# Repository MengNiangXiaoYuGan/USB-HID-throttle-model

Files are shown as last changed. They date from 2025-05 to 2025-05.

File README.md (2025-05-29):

# USB-HID-throttle-model

该仓库作为USB-HID-throttle项目的模型仓库,仓库内文件夹结构如下

|

|\  模型        //用于放置需要打印的文件

|   

|-  LICENSE     //许可证文件

|

|-  MNXYG_出图-装配.pdf     //总装配的工程图，五金件表单以及打印要求和热嵌螺母安装位也在里面

另外，为了制造具有完整功能的USB-HID节流阀，还需要制造电路板以及下载程序。
电路板程序可以从以下仓库获得
https://github.com/MengNiangXiaoYuGan/USB-HID-throttle-PCB.git

程序源码可以在以下仓库获得，或者在电路板仓库中直接使用已经编译好的bin文件
https://github.com/MengNiangXiaoYuGan/USB-HID-throttle-program.git

祝，使用愉快，有问题请反馈，有闲心会看一下

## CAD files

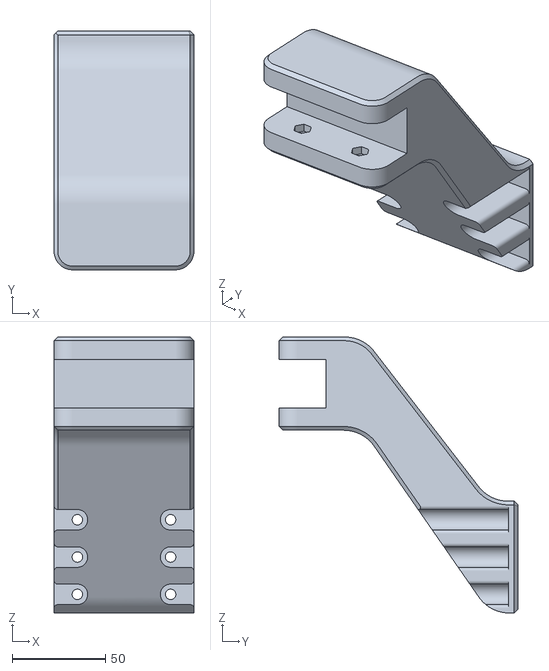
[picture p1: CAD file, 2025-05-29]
模型/私有油门-桌面连接件-M5大小.stl
75.0 x 128.0 x 148.0

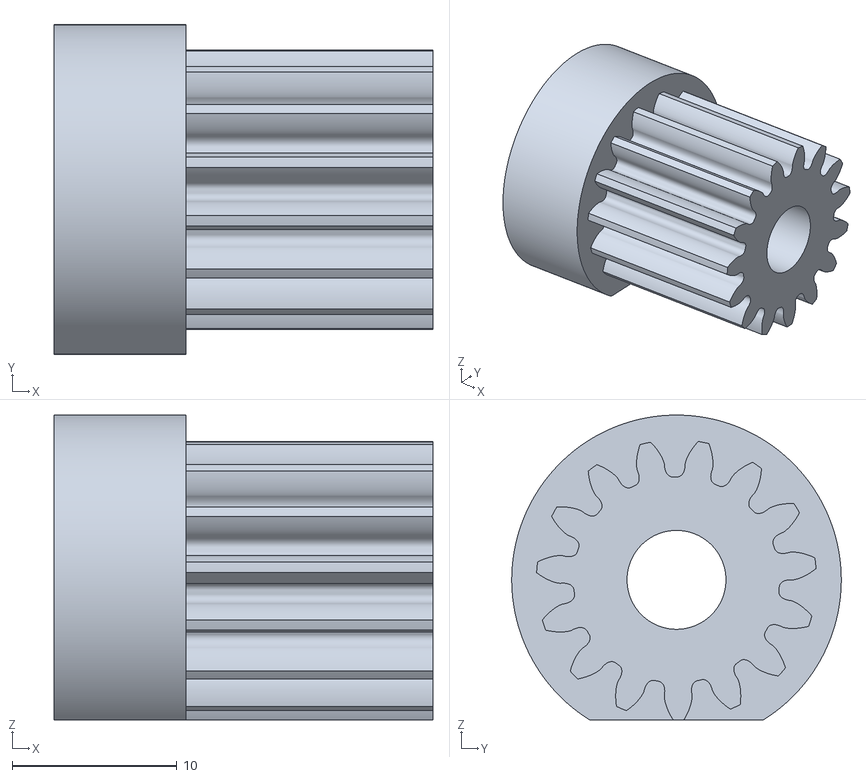
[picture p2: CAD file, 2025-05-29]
模型/电位器齿轮.stl
23.0 x 20.0 x 18.5

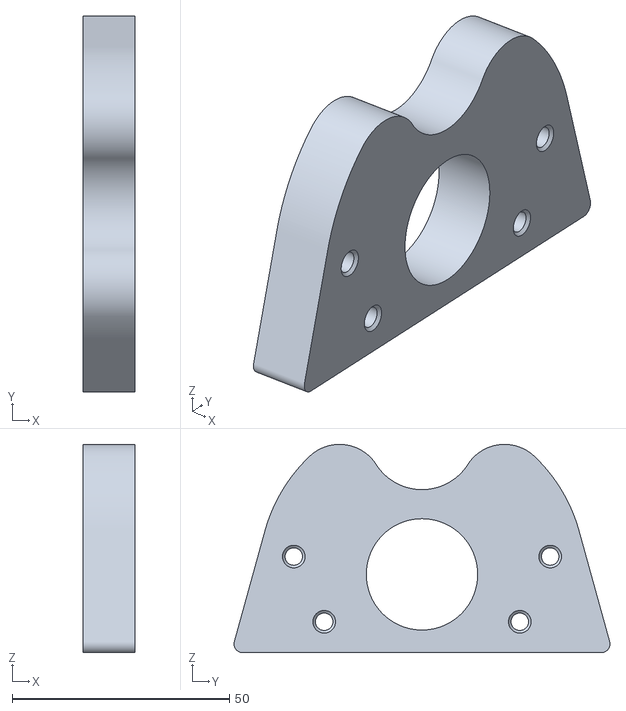
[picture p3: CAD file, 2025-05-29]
模型/底座-油门连接杆-环套.stl
12.0 x 86.5 x 47.9

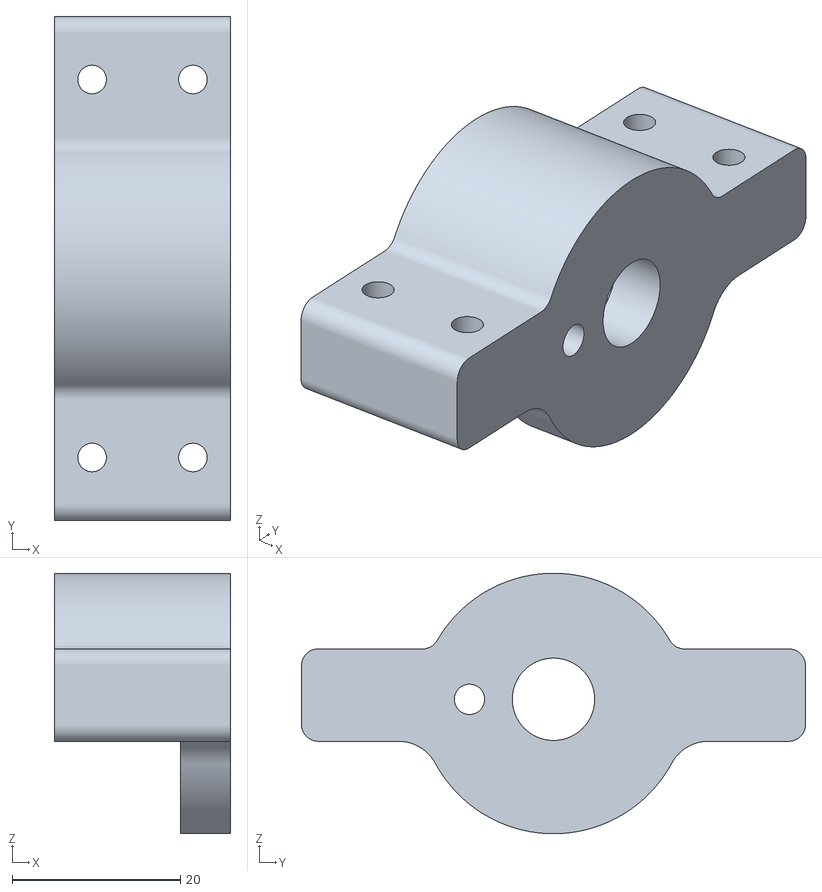
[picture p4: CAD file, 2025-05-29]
模型/电位器-连接件.stl
21.0 x 60.0 x 31.0

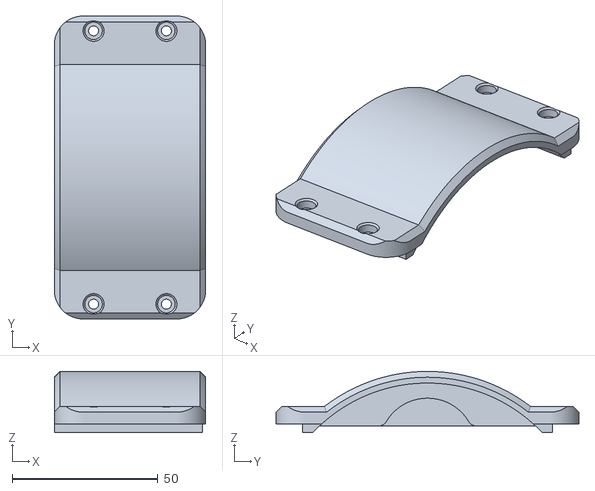
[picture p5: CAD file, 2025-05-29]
模型/底座-电位器齿轮上盖.stl
52.0 x 104.0 x 21.0

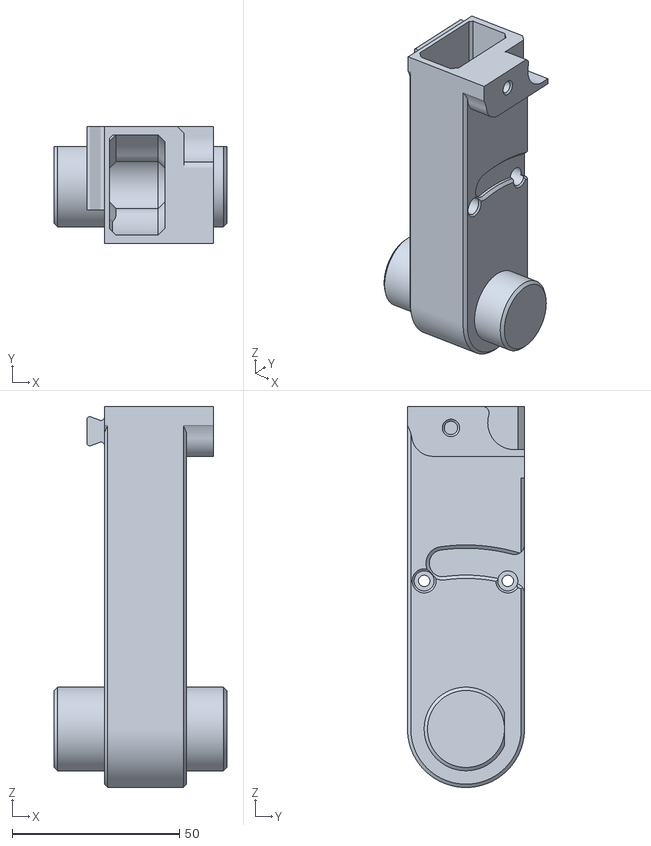
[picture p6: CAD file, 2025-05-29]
模型/手把-连接杆.stl
51.6 x 35.0 x 113.9

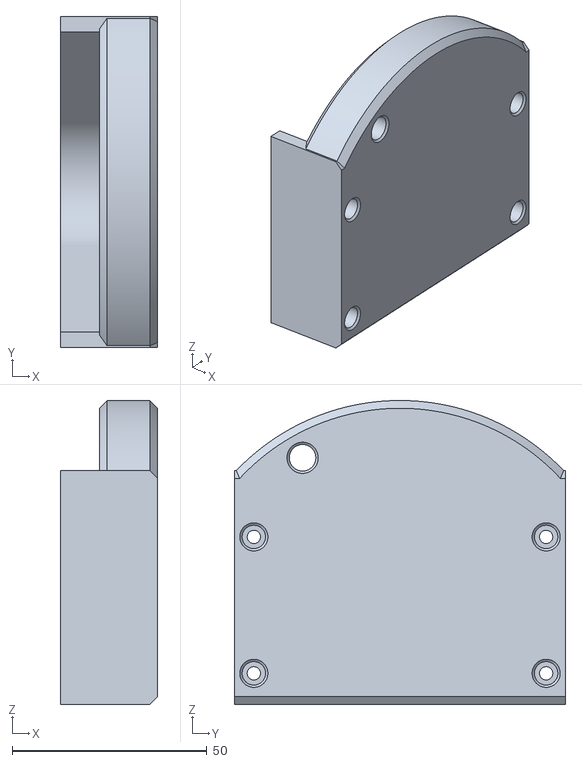
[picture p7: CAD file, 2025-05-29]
模型/底座-油门连接杆-外封.stl
25.0 x 85.0 x 78.0

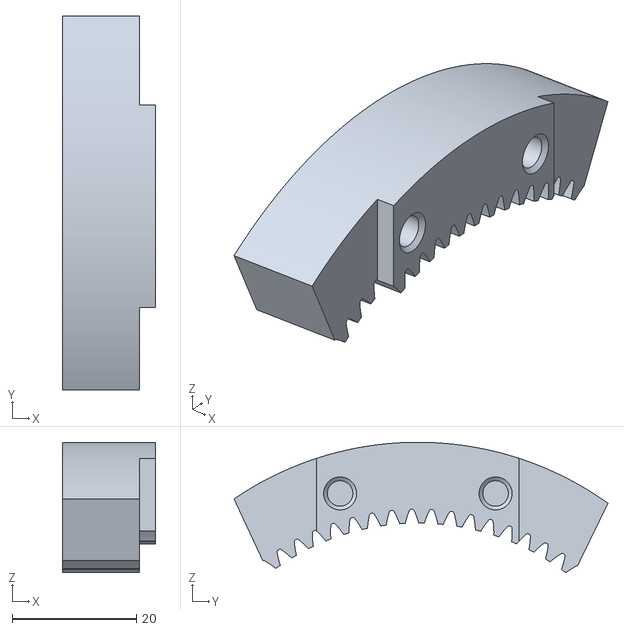
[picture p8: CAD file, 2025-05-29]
模型/手把-主动齿条.stl
15.0 x 60.1 x 21.0

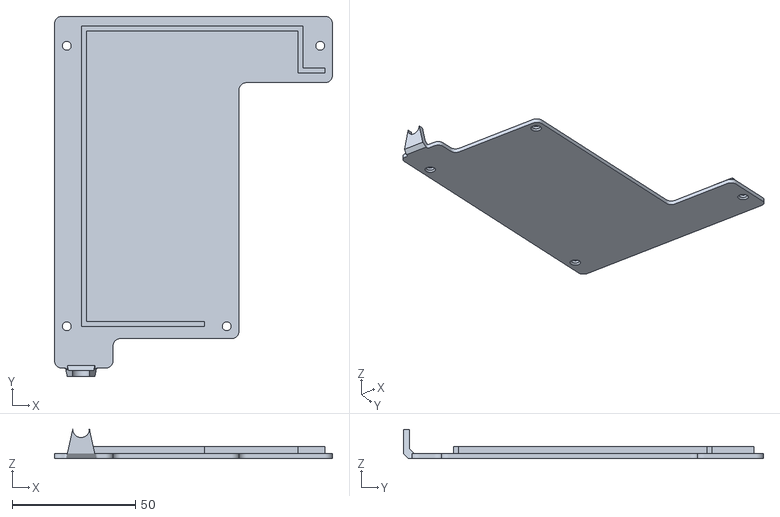
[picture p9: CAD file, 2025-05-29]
模型/底座-下盖.stl
113.0 x 146.5 x 11.9

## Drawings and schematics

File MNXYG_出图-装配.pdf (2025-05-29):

# USB

# HID

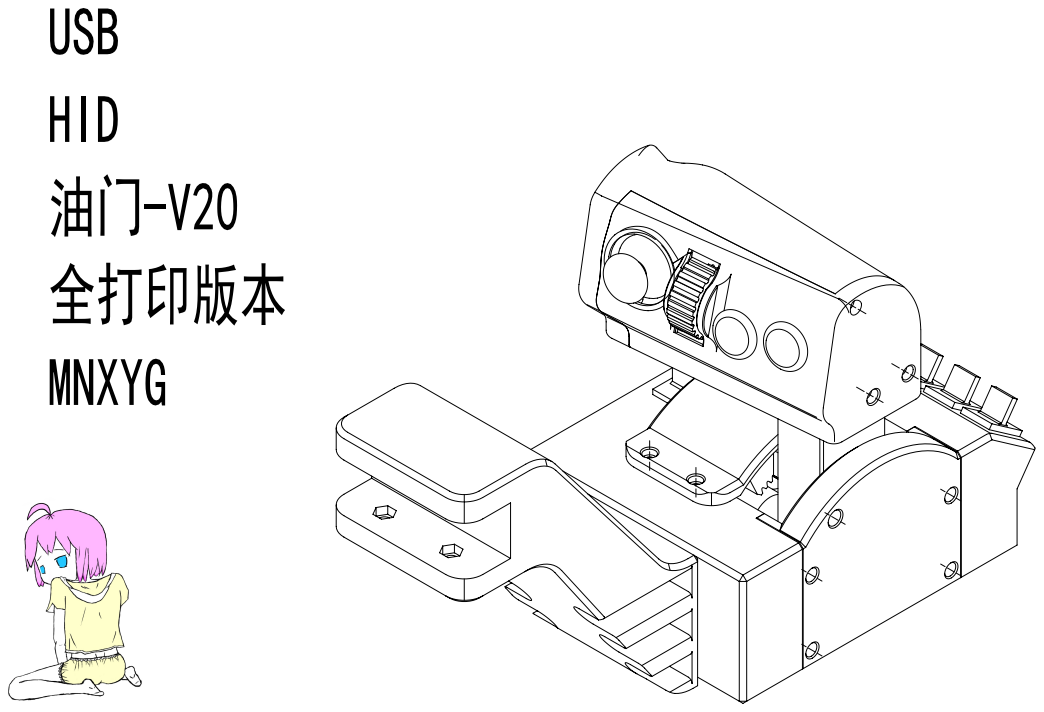
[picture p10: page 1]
全打印版本 MNXYG

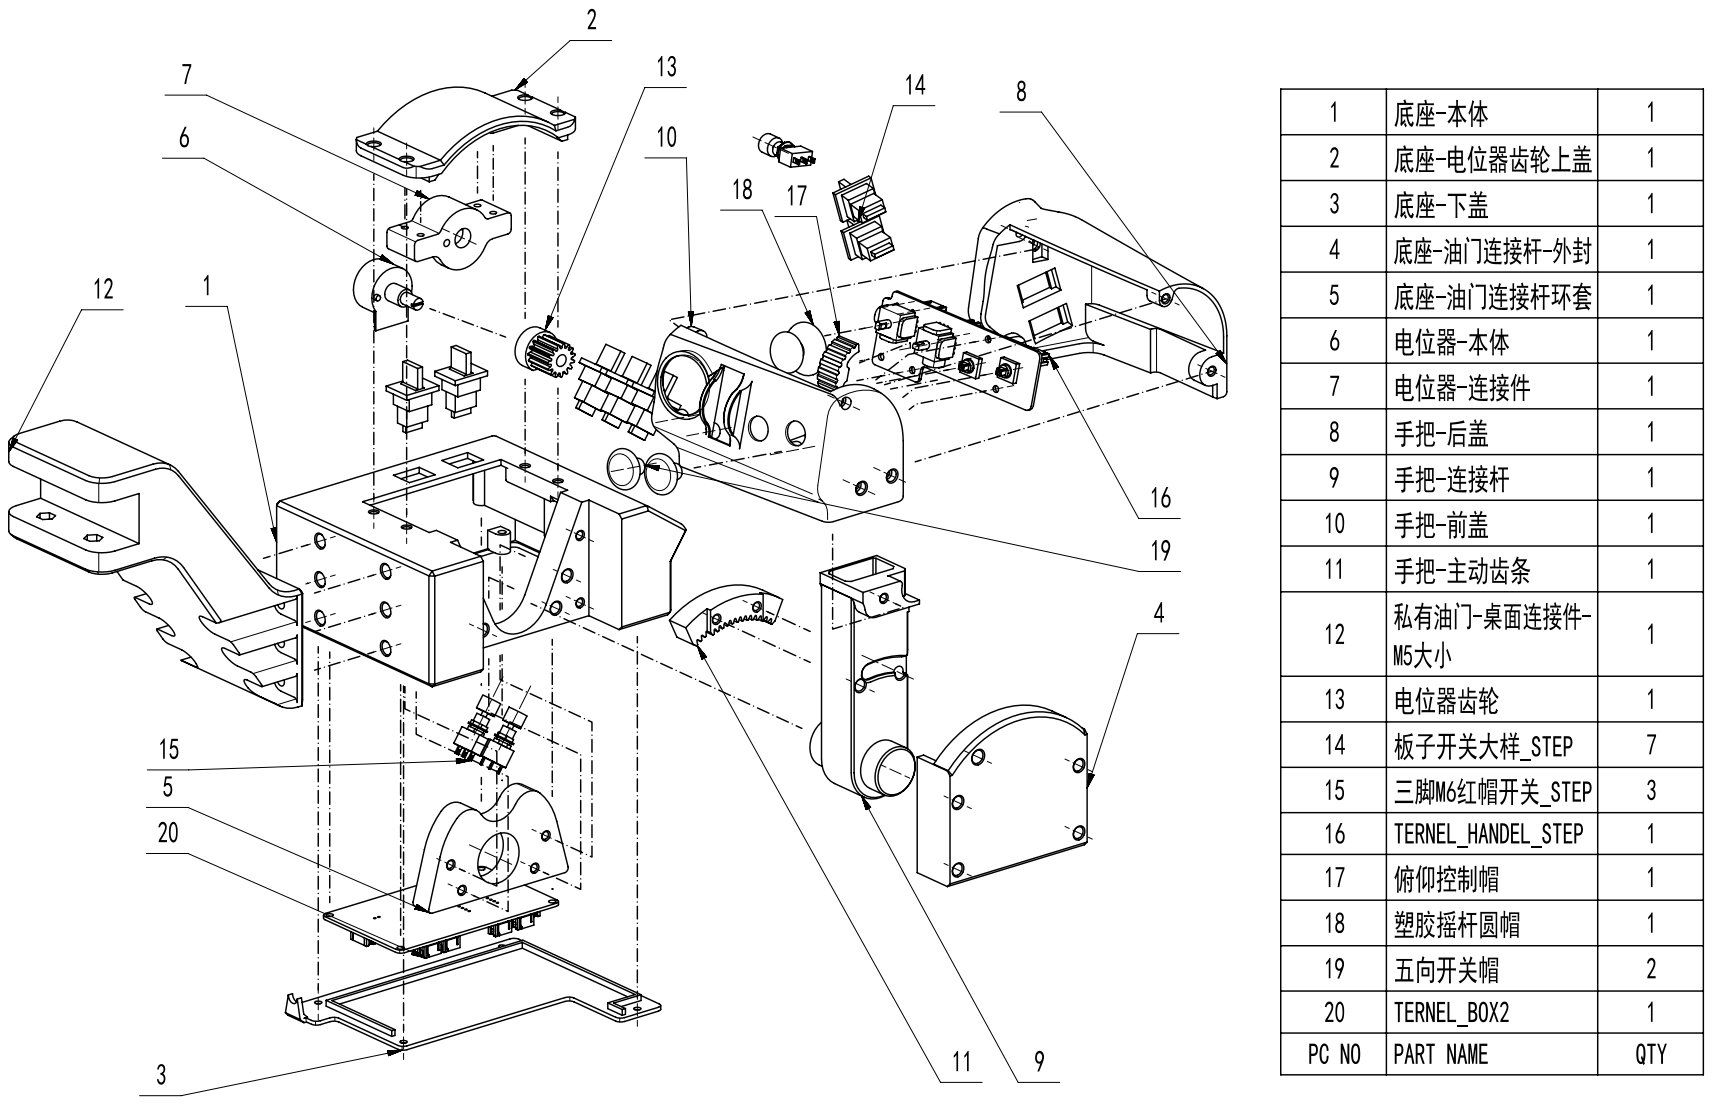
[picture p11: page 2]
底座-电位器齿轮上盖; 底座-油门连接杆-外封; 底座-油门连接杆环套; 电位器-本体; 电位器-连接件; 手把-连接杆; 手把-主动齿条; 私有油门-桌面连接件-; 电位器齿轮; 板子开关大样_STEP; 三脚M6红帽开关_STEP; TERNEL_HANDEL_STEP; 俯仰控制帽; 塑胶摇杆圆帽; 五向开关帽; TERNEL_BOX2; PART NAME; QTY

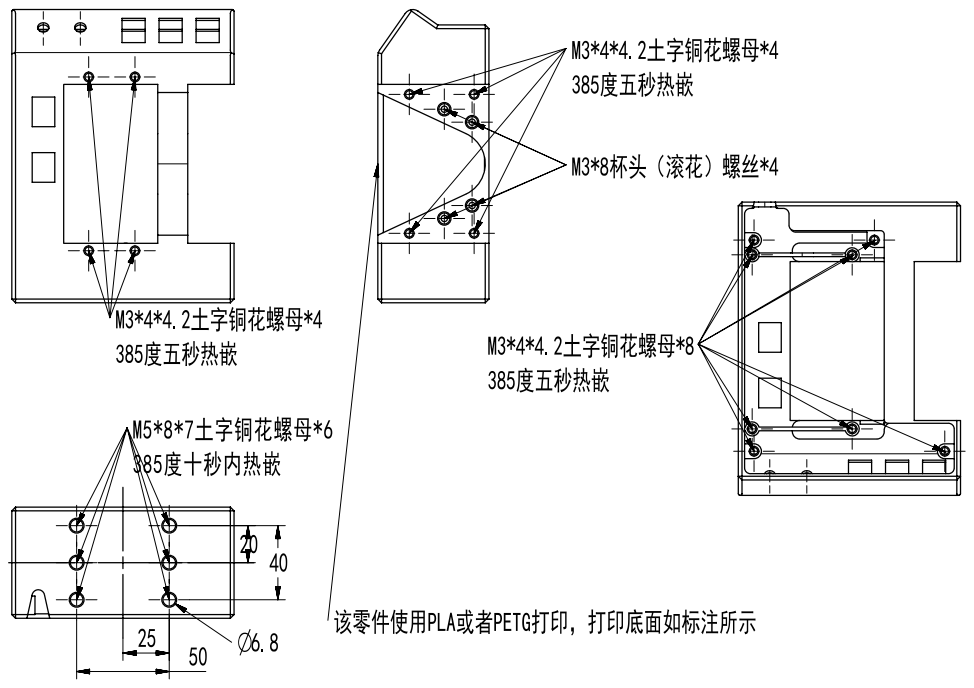
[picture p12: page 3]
M5*8*7土字铜花螺母*6; 385度十秒内热嵌; M3*4*4.2土字铜花螺母*4; 385度五秒热嵌; M3*4*4.2土字铜花螺母*8; 该零件使用PLA或者PETG打印，打印底面如标注所示

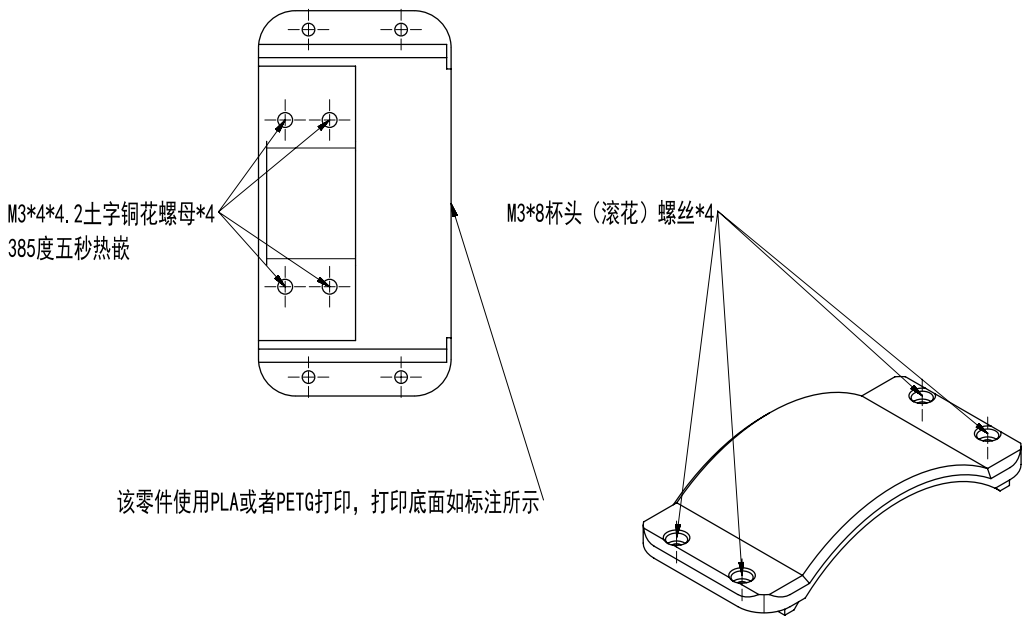
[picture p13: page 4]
M3*4*4.2土字铜花螺母*4; 385度五秒热嵌; 该零件使用PLA或者PETG打印，打印底面如标注所示

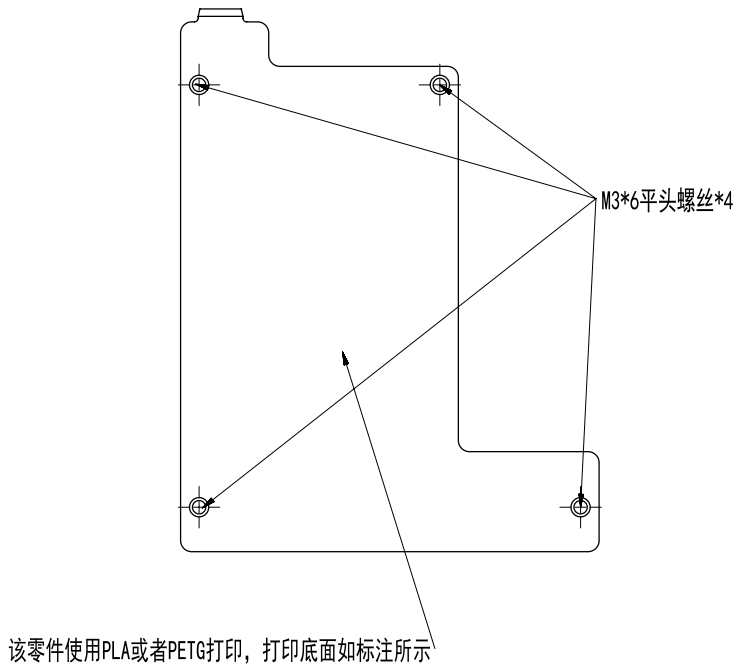
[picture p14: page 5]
M3*6平头螺丝*4; 该零件使用PLA或者PETG打印，打印底面如标注所示

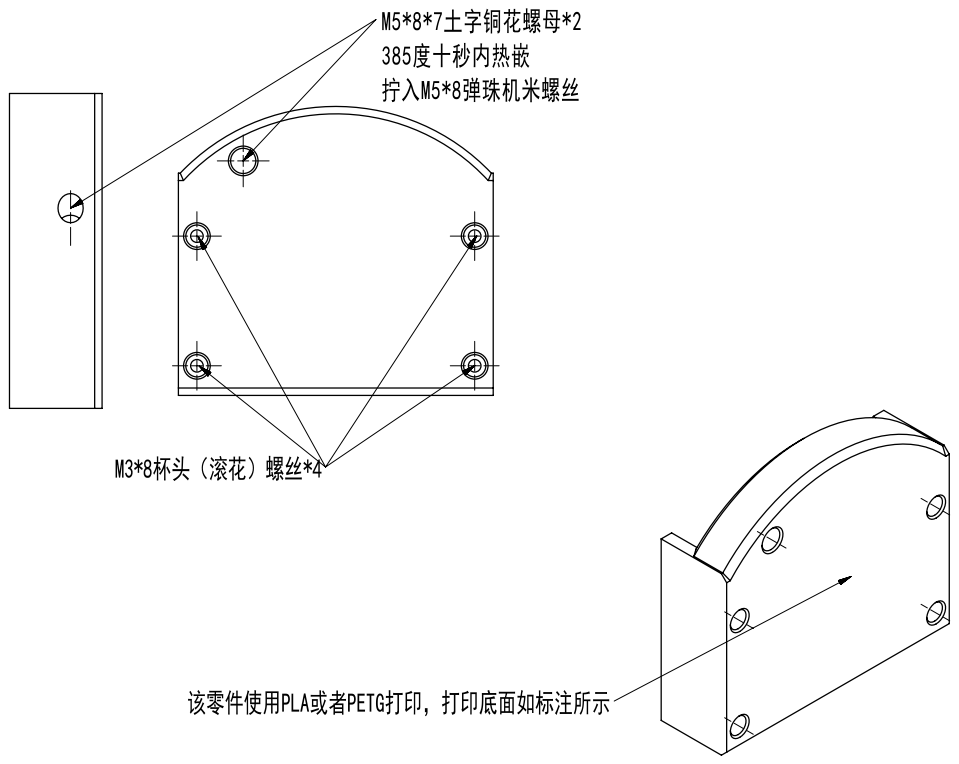
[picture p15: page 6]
该零件使用PLA或者PETG打印，打印底面如标注所示; M5*8*7土字铜花螺母*2; 385度十秒内热嵌 拧入M5*8弹珠机米螺丝

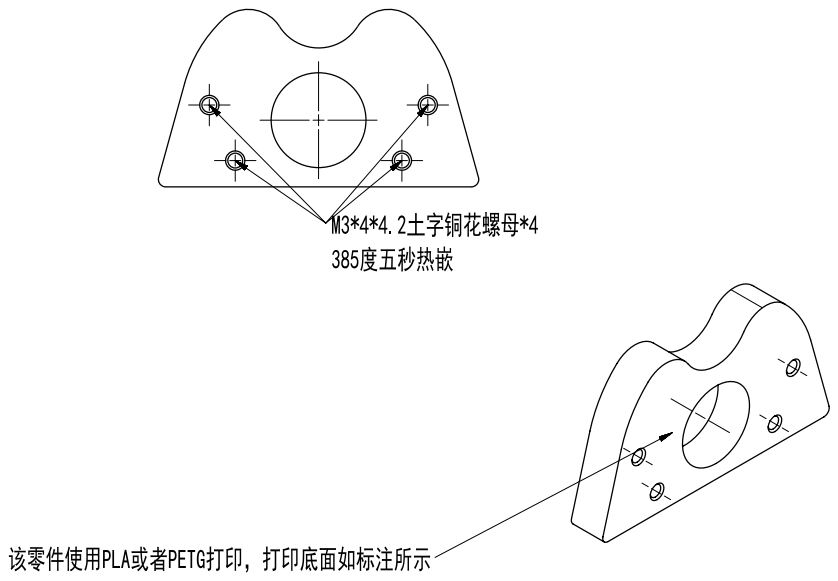
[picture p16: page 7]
该零件使用PLA或者PETG打印，打印底面如标注所示; M3*4*4.2土字铜花螺母*4; 385度五秒热嵌

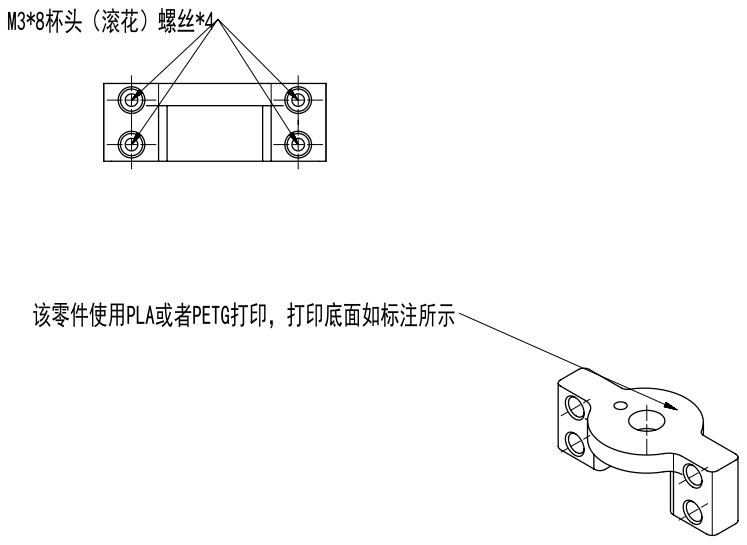
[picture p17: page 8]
该零件使用PLA或者PETG打印，打印底面如标注所示

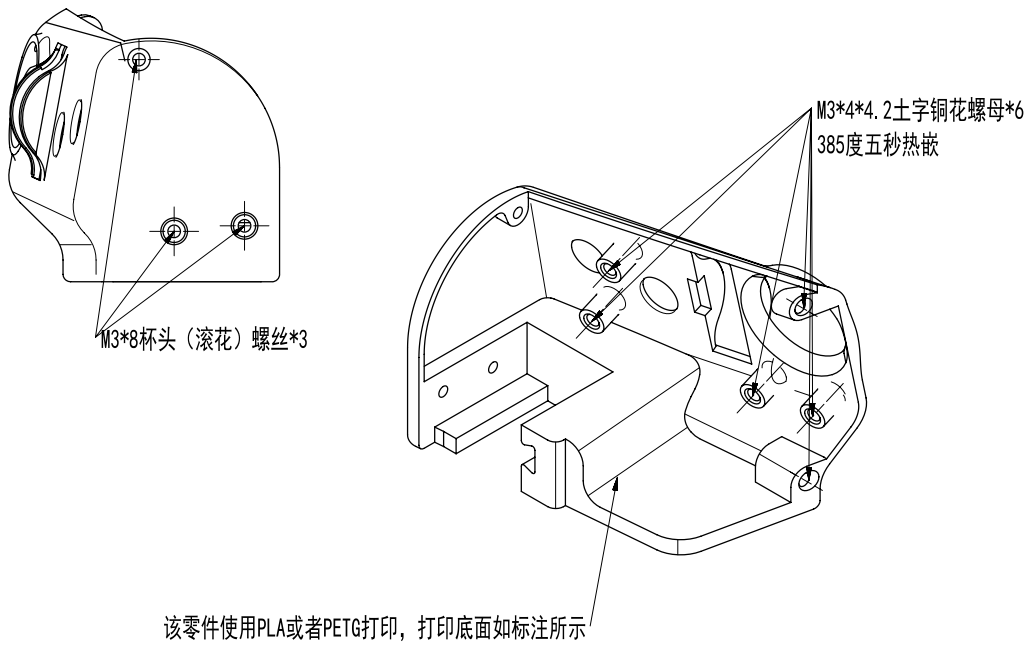
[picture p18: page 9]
M3*4*4.2土字铜花螺母*6; 385度五秒热嵌; 该零件使用PLA或者PETG打印，打印底面如标注所示

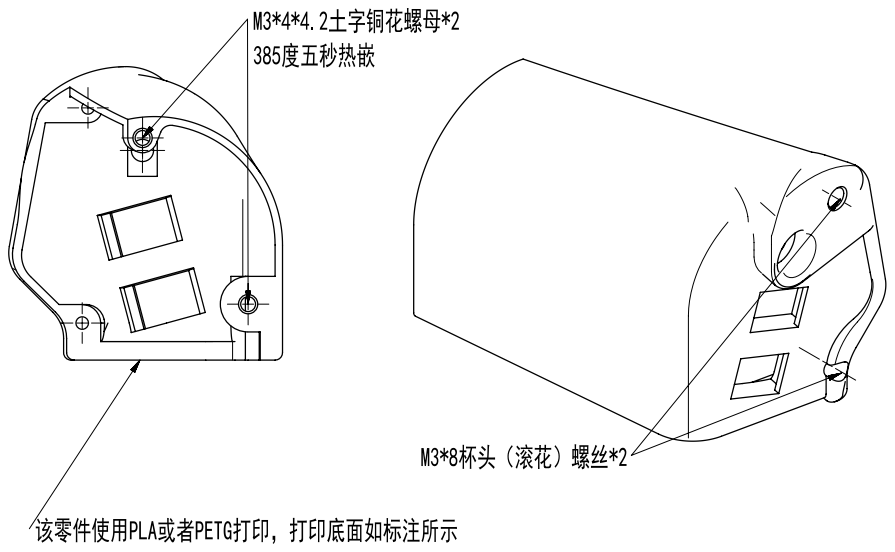
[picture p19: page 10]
M3*4*4.2土字铜花螺母*2; 385度五秒热嵌; 该零件使用PLA或者PETG打印，打印底面如标注所示

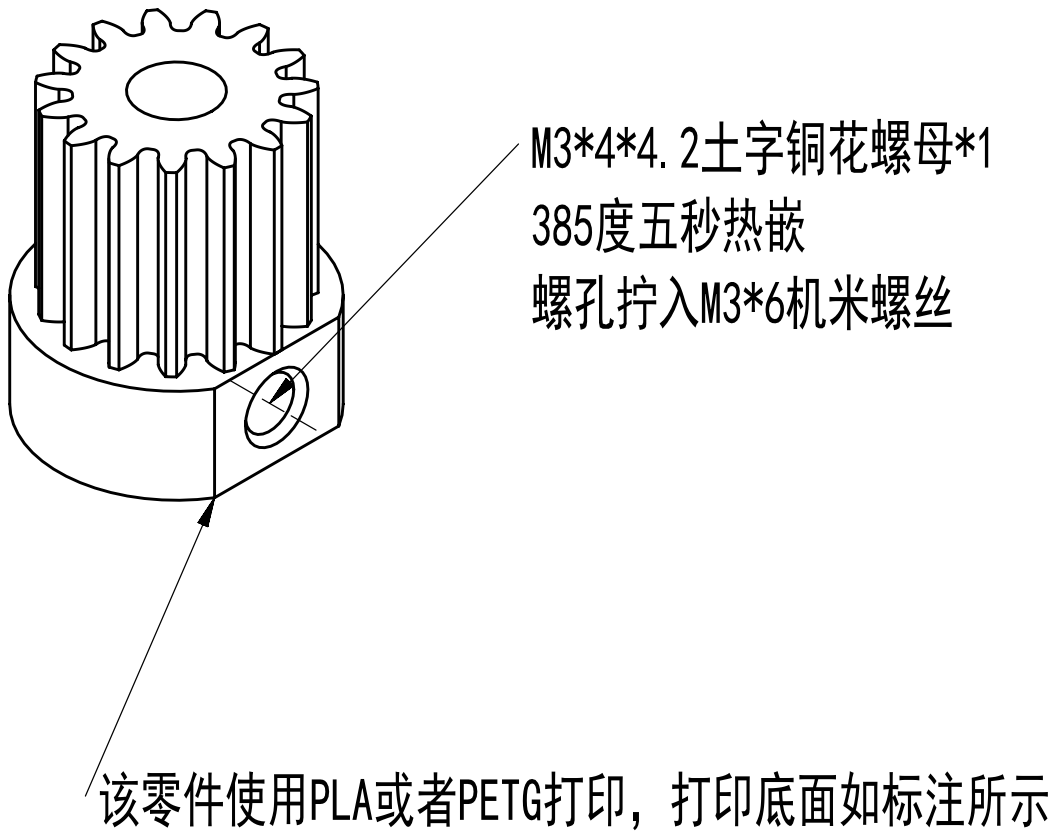
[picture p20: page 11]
M3*4*4.2土字铜花螺母*1; 385度五秒热嵌 螺孔拧入M3*6机米螺丝; 该零件使用PLA或者PETG打印，打印底面如标注所示

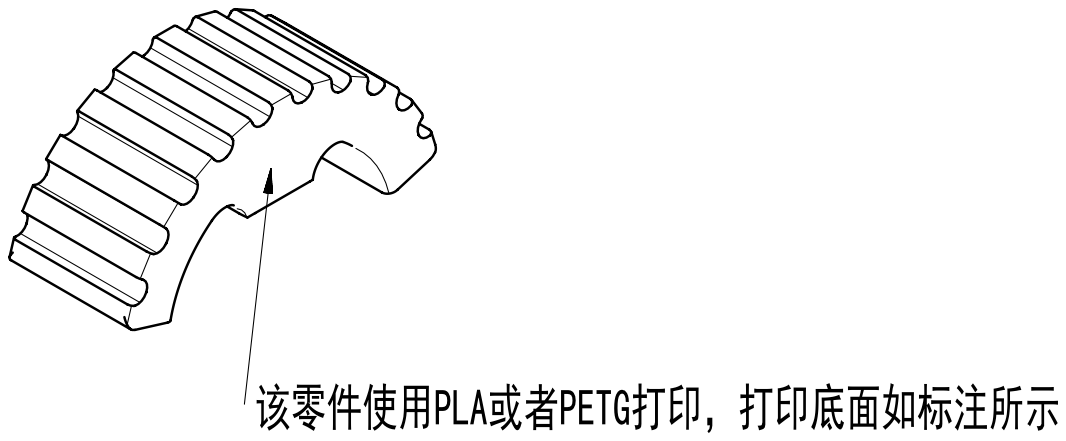
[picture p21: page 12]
该零件使用PLA或者PETG打印，打印底面如标注所示

该零件使用PLA或者PETG打印，打印底面如标注所示; M3*4*4.2土字铜花螺母*2; 385度五秒热嵌

该零件使用PLA或者PETG打印，打印底面如标注所示A; SECTION A-A

该零件使用PLA或者PETG打印， 如果使用pla打印; 其壁厚需要达到1.2mm 填充超过20%， petg无要求，使用最常用的设置即可; 打印底面如标注所示; M5国标六角螺母*2; 直接放入; M5手拧螺丝*2; 螺纹长超过20mm; M5*12圆头螺丝*6; 该零件用于将油门固定至厚度不超过24MM的桌面边缘; 如果你有更好的固定方式或者已经拥有支架，则这个件可以省略不打

拇指按键 用ph2.0*3单头线; 剩下一根剪掉即可; 建议将线绞为双绞线; 按键接线; 减速板开关 用ph2.0*3单头线; 按照顺序连接至板子开关; 右-右或者反向; 建议绞成三绞线; 开关接线; 辅助开关; CN1-CN4 使用ph2.0*6P-30CM公对公反向线逐一连接; 如果使用单头线对焊 则线长建议在20cm单根; 同色焊接; VR1 ph2.0*3P单头线; 依次连接电位器的三个引脚; 只需要保证中-中即可; 板子开关*3; 可与另外开关互换位置; 板子开关*2; 可互换; USB公头线 ph2.0 4P接口; 从左到右线序为 GND D+ D- VCC; 程序下载细节及注释; 请查阅电路部分仓库

备用-小指开关（未连接

中央线与任意一根分别连接至
按键COM（公共端）和NO（常开端）

五金件-标准零件表

项目 | | | 型号 | 数量 | 备注
双边自复位板子开关 | RLS-123-F1 红色（黑色）手柄 | | | 7
MTS102红头开关 | | MTS102-3脚红头自复位 | | 3

单圈碳膜电位器 | | RV24YN-100-10K | | 1

3D摇杆帽 | | NA | | 1 | 跟着摇杆电位器配就是了
螺丝 | | M3*8杯头（滚花） | | 50 | 可以多买点-下同
螺丝 | | M3*6平头 | | 50
螺丝 | | M5*12圆头 | | 10
热嵌螺母 | | M3*4*4.1(4.2)土字滚花螺母 | | 50
热嵌螺母 | | M5*8*7土字滚花螺母 | | 20
机米螺丝 | | M5*8弹珠 | | 5

机米螺丝 | | M3*6 | | 5

六角螺母 | | M5 | | 10

手拧螺丝 | | M5*30 | | 10
线材 | | PH2.0*3P公头单头线-15CM | | 20
线材 | | PH2.0*6P公头双头线(反向)-30CM | | 10
线材 | | usb公头线-ph2.0-4p 1M以上 | | 1

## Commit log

2025-05-29 上传最初文件-模型以及装配出图
    [底座-下盖.stl, 底座-油门连接杆-外封.stl, 底座-油门连接杆-环套.stl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]
2025-05-29 “修改README”
